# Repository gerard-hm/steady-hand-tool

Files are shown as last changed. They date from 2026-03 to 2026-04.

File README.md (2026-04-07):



# Steady Hand Tool

> “When you're racing against your own biology, the **story** is just the exhaust; the **science is the engine** and time is the fuel.”

<p align="center">
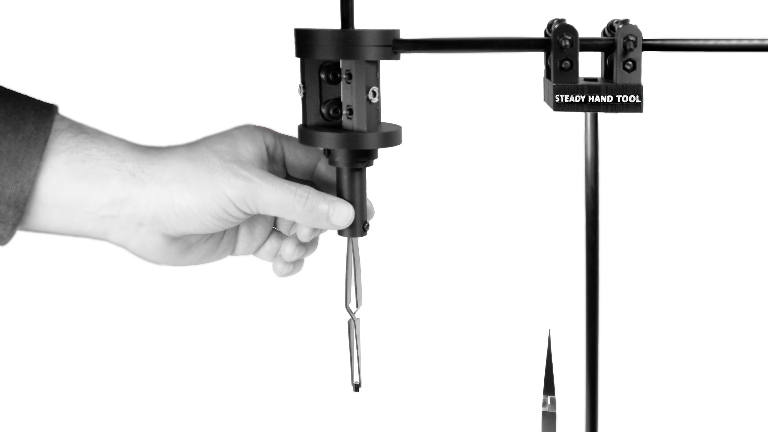
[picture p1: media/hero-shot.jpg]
  
  <br>
</p>
<p align="center">
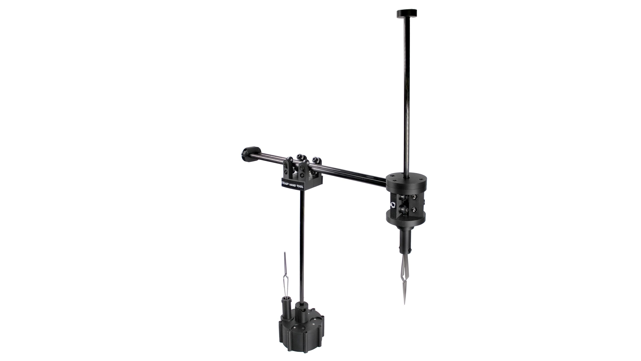
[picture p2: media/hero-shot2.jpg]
  
  <br>
</p>
<p align="center">
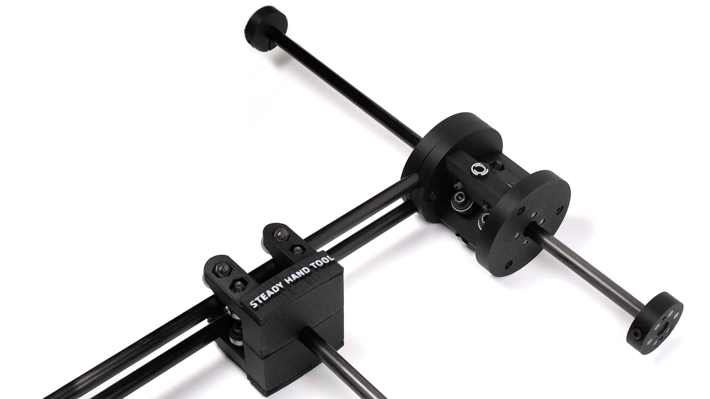
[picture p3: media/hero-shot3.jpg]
  
  <br><br><br>
  <em>Steady Hand Tool: Mechanical stability for a wandering hand.</em>
</p>

## See it in Action
<p align="center">
  <a href="https://www.youtube.com/watch?v=Imng8o2QRBg">
    Steady Hand Tool Video
  </a>
  <br>
  <em>Demonstrating the stability and precision of the Steady Hand Tool.</em>
</p>

---

Steady Hand Tool is a manual SMD (Surface Mount Device) assembly stabilizer designed to help makers and professionals prototype PCBs with high precision. Originally created to overcome physical challenges—specifically hand tremors caused by Parkinson’s disease—this tool makes high-accuracy soldering accessible to everyone.

## 🌟 Key Features

* **Stabilized 4-DOF Movement:** Keeps your hand on a steady track while allowing full vertical and horizontal reach.
* **Near-Zero Friction:** Equipped with **14 high-quality metal bearings** and carbon fiber rods for smooth, silent, and effortless operation.
* **Modular Magnetic Coupler:** Features a quick-swap magnetic system for changing tool heads (tweezers, vacuum tips, etc.) in seconds.
* **Purely Mechanical:** No power required, no cables, and no noise. It's always ready to work when you are.
* **Heavy-Duty Base:** A weighted **680g (1.5 lb)** base ensures the arm remains stable even at full extension.
* **Open Source:** Designed to be hacked and customized. Create your own tool heads to suit your specific workflow.

## 🚀 Get Yours

<p align="center">
  <a href="https://www.crowdsupply.com/halfmarble/steady-hand-tool">
    
  </a>
</p>

<p align="center">
  <b>The Steady Hand Tool is coming to <a href="https://www.crowdsupply.com/halfmarble/steady-hand-tool">Crowd Supply</a>.</b><br>
  Sign up to be notified when the campaign launches.
</p>

---

## 🛠 Technical Specifications

* **Reach:** Approximately 250 mm (9.8 in) vertical and horizontal travel.
* **Construction:** 3D-printed components (optimized for PETG/Carbon Fiber) and 8mm carbon fiber rods.
* **Bearings:** MR128ZZ precision shielded bearings.
* **Compatibility:** Designed to support a pair of specialized reverse tweezers optimized for 0805-size components and smaller.

> [!TIP]
> **Looking to build it?** Check out our [Assembly Guide](https://github.com/gerard-hm/steady-hand-tool/blob/main/docs/assembly-guide.md) for step-by-step instructions.

## 📂 Repository Structure

```
steady-hand-tool/
├── .github/                # Issue templates and GitHub-specific config
├── hardware/               # All physical design files
│   ├── models/             # 3D models for printing
│   │   ├── stl/            # Ready-to-print files (standard)
│   │   │   ├── 3rdParty/   # Adapters for 3rd party tools
│   │   ├── step/           # High-fidelity files for CAD software
│   │   └── community/      # User-submitted tool heads
│   ├── electronics/        # (Optional) If you ever add sensors/LEDs
│   └── reference/          # Technical drawings or dimension sheets
├── docs/                   # Documentation and guides
│   ├── assembly-guide.md   # Step-by-step build instructions
│   ├── images/             # Photos and GIFs used in the guides
│   └── calibration.md      # How to tune the arm for smooth movement
├── media/                  # High-res logos and marketing photos
├── .gitignore              # Tells Git which files to ignore (like temp CAD files)
├── BOM.md                  # Bill of Materials (the "Shopping List")
├── CONTRIBUTING.md         # How others can help
├── LICENSE                 # CERN-OHL-S-2.0 License text
└── README.md               # The front page of your project
```

---

## ⚙️ Our Mission

"It's the only tool that I have, to help me and others manage our own **slice of PD hell.**"

The Steady Hand Tool is an engineering response to a personal biological war. It exists because "making" is a vital part of staying human. Inspired by the lived reality of Parkinson’s Disease, this tool is engineered to ensure that biological constraints never dictate the boundaries of human creativity.

## 🔧 Our Support

This is a race against time and biology. We invite you to pick up a wrench and help us optimize the hardware for the next generation of makers facing similar constraints. Feedback, CAD iterations, and mechanical refinements are the high-octane fuel that keeps this engine running.

<p align="left">
  <a href="https://give.michaeljfox.org/give/421686/#!/donation/checkout">
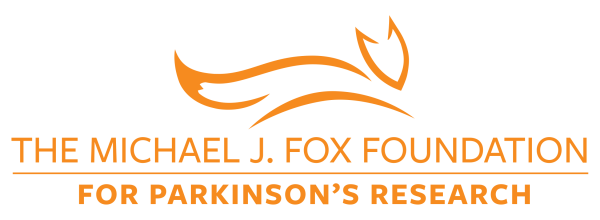
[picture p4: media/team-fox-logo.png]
Team Fox Logo
    
  </a>
  <br>
  <em>If this tool has been helpful to you, please consider supporting the <b>Michael J. Fox Foundation</b> in their mission to find a cure for Parkinson’s.</em>
</p>

---

## License

This project is licensed under the [**CERN-OHL-S-2.0 License**](https://choosealicense.com/licenses/cern-ohl-s-2.0/) - see the [LICENSE](LICENSE) file for details.

---

## Credits

**Photography:** Hero images provided by [Crowd Supply](https://www.crowdsupply.com).

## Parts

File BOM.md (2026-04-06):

# Steady Hand Tool

**A stabilizing pick-and-place arm for precision SMD assembly.**




<p align="center">
  Steady Hand Tool v1
  <br>
  <em>Steady Hand Tool — when you need help holding down really tiny parts.</em>
</p>

---

## 🛒 Bill of Materials (BOM)

The Steady Hand Tool is designed for easy sourcing. You can find the links and visual references for each component below (please notice that these are affiliate links).

### 🏗️ Structural Hardware

| Image | Item | Specification | Purpose |
| :---: | :--- | :--- | :--- |
|  | [**Carbon Fiber Rods**](https://amzn.to/4jpyyZC) | 8mm Diameter x 300mm | Main vertical and horizontal rails |
|  | [**MR128ZZ Bearings**](https://amzn.to/42kMWMD) | 8x12x3.5mm (14 required) | Frictionless carriage movement |
|  | [**Magnets**](https://amzn.to/4hq1puZ) | 4mm x 2mm Neodymium | Magnetic tool coupler interface |
|  | [**Base Weights**](https://amzn.to/4armCCl) | Metal BBs or Bearing Balls | Ballast to prevent tipping |

### 🔩 Fasteners

| Image | Item | Specification | Purpose |
| :---: | :--- | :--- | :--- |
|  | [**M3 Hardware**](https://amzn.to/42phRHt) | Stainless Steel M3 Bolts/Nuts | Structural assembly of the base and arm |
|  | [**M4 Hardware**](https://amzn.to/3WslSXP) | Stainless Steel M4 Bolts/Nuts | Structural assembly of the base and arm |

### 🔧 Tools

| Image | Item | Specification | Purpose |
| :---: | :--- | :--- | :--- |
|  | [**Reverse Tweezers**](https://amzn.to/4g4LjWo) | Needle-point, locking | Holding SMD parts during placement |
|  | [**Ball-Hex Drivers**](https://amzn.to/4jlawie) | Metric Allen Key Set | Recommended for assembly |

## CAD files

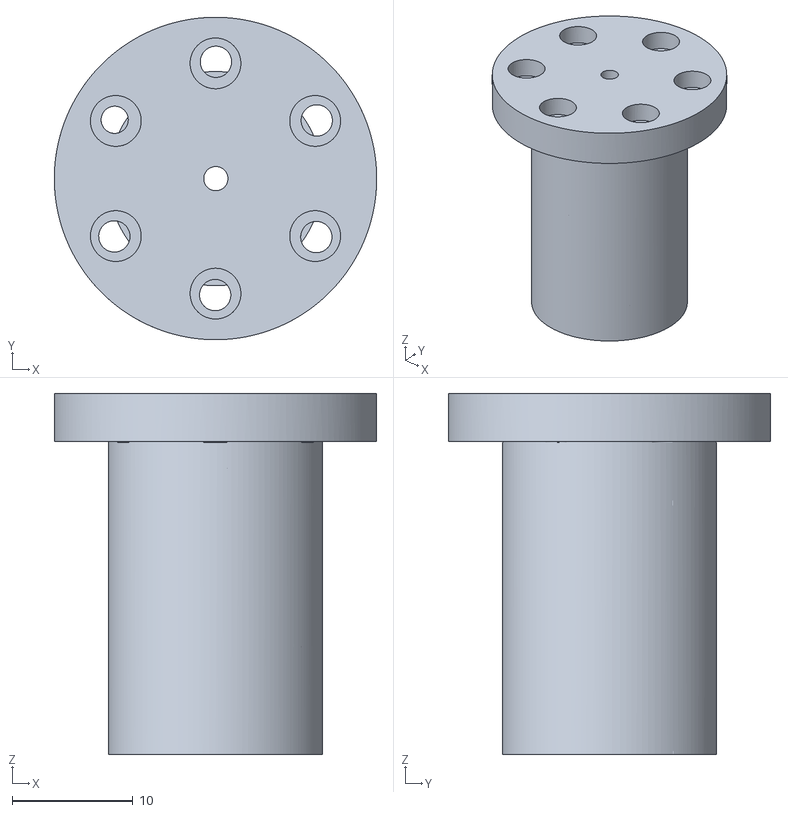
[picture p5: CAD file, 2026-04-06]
hardware/models/stl/InterfaceManualVacuumPen.stl
26.7 x 26.7 x 29.9

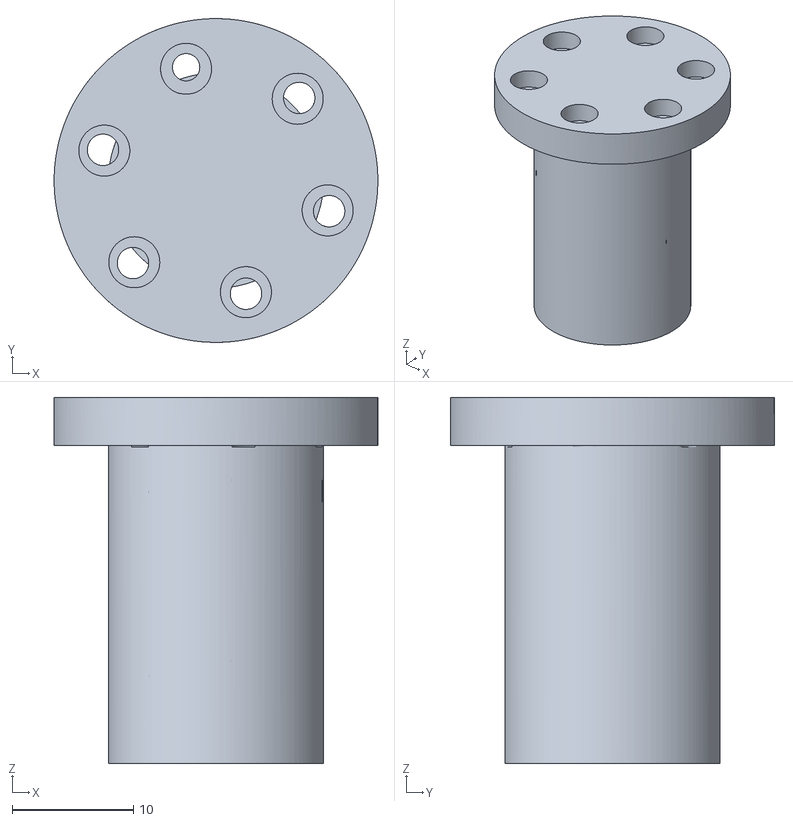
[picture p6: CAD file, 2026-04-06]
hardware/models/stl/InterfaceTemplate.stl
26.7 x 26.7 x 30.1

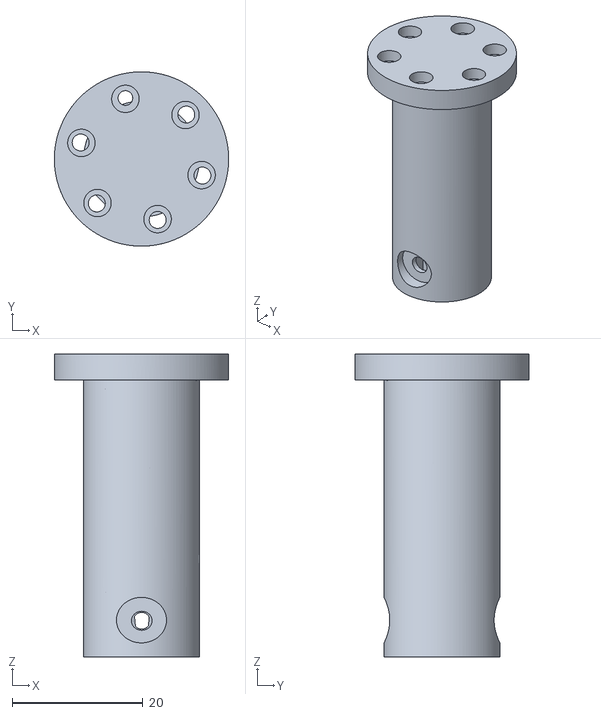
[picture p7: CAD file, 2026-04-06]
hardware/models/stl/InterfaceTweezers.stl
26.7 x 26.7 x 46.3

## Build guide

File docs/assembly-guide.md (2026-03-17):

# Steady Hand Tool Assembly Guide - Part 1

This assembly guide is based on the [Steady Hand Tool DIY Part 1](https://www.youtube.com/watch?v=_OBHK19EvW4) video tutorial.

**Estimated Time:** 30 Minutes

---

## 🛠️ Required Tools
* **2.5mm** Hexball screwdriver
* **3.0mm** Hexball screwdriver

---

## 🔩 Preparation: Fasteners Sorting
Before starting, sort your bolts into two main piles based on their diameter and length:
* **M3 Bolts** (Thinner)
* **M4 Bolts** (Thicker)

---

## 🧩 Assembly Steps

### Step 1: Weight the Base
* Fill the internal cavities of the 3D-printed base with metal weights (beads/balls) to ensure stability during use.

### Step 2: Sorting Bolts
* Differentiate between M3 and M4 bolts to avoid mistakes in later steps.

### Step 3: Close the Base
* **Parts:** 5x M4x16 bolts, 1x M4 nut.
* Secure the base cover using the M4 bolts.

### Step 4: Prepare the Bearings
* **Parts:** 14x M4x16 bolts and 14x M4 nuts.
* **Assembly Order:** Thin spacer ➡️ Metal bearing ➡️ Fat spacer.
* Repeat this for all 14 bearing sets.

### Step 5: Horizontal Cage (Part A)
* **Parts:** 8 prepared bearing sets.
* Insert the bearing sets into the horizontal cage housing.

### Step 6: Horizontal Cage (Part B)
* **Parts:** 4x M4x16 bolts and 4x M4 nuts.
* Secure the cage assembly.
* **Pro Tip:** Use a long M3x20mm bolt as a temporary tool to guide and hold M3 nuts in place for tight spots.

### Step 7: Vertical Cage (Part A)
* **Parts:** 6 prepared bearing sets.
* Assemble the bearing sets into the vertical cage components.

### Step 8: Vertical Cage (Part B)
* **Parts:** 3x M3x16 bolts, 3x M3x20 bolts, 1x M4x10 bolt, 1x M4 nut.
* Join the vertical cage components and attach the vertical rods.
* **Note:** Use the single short **M4x10mm** bolt specifically for the rod interface.

### Step 9: Horizontal Stop
* **Parts:** 2x M3x16 bolts and 2x M3 nuts.
* Assemble and slide the stop onto the horizontal rods.

### Step 10: Vertical Stop
* **Parts:** 1x M3x16 bolt and 1x M3 nut.
* Install the stop onto the vertical rod to limit the tool's travel.

### Step 11: Interface Ring
* **Parts:** 2x M3x10 bolts and 2x M3 nuts.
* Secure the ring that interfaces with the tool head.

### Step 12: Tool Interface
* **Parts:** 2x M3x8 bolts and 2x M3 nuts.
* Install the final interface component that will hold your specific tool.

### Step 13: Branding
* Install the **Steady Hand Tool** and **Half Marble** logo plates into their designated slots.

---

**Next Step:** Watch Part 2 to learn how to install the magnets for the base and interface.

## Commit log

2026-03-16 add BOM
2026-03-16 Revise BOM for Steady Hand Tool with new features
    Updated the Bill of Materials (BOM) to include new sections and features for the Steady Hand Tool, along with structural hardware and fasteners details.
2026-03-16 Update image paths in BOM.md to use media directory
2026-03-16 Remove DIY Kits and BOM sections from README
    Removed the DIY Kits & Assembly section and Bill of Materials from the README.
2026-03-16 Resize Team Fox logo in BOM.md
2026-03-17 Remove sections from BOM.md
    Removed key features, repository structure, mission, and license sections from BOM.md.
2026-03-17 Refactor BOM.md to improve structure and clarity
    Removed introductory description of the Steady Hand Tool and reorganized the BOM sections to separate fasteners and tools.
2026-03-17 Revise affiliate links in Bill of Materials
    Updated affiliate links for components in the BOM.
2026-03-17 Add assembly guide for Steady Hand Tool - Part 1
    This guide provides detailed assembly steps for the Steady Hand Tool, including required tools and preparation instructions.
2026-03-17 Update Assembly Guide link in README
2026-03-31 Update magnet specifications in BOM.md
2026-04-06 add more tool interfaces
    [InterfaceManualVacuumPen.stl, InterfaceTemplate.stl, InterfaceTweezers.stl]

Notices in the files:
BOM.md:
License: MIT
